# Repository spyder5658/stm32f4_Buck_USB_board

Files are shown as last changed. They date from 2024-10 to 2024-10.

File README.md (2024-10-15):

# STM32F4-Based 4 layered Board with Dual Power Supply and Protection Features
## Overview
This project showcases a custom STM32F4-based board designed with robust power management and advanced PCB architecture. The board features dual power supply options, reverse polarity protection, a buck converter, and a power indicator LED. Additionally, it boasts a 4-layer PCB design, enhancing signal integrity and ensuring efficient power distribution, making it ideal for high-performance embedded systems.

## Key Features
- Microcontroller: STM32F4 series (ARM Cortex-M4)
- 4-Layer PCB Design:
  - Improved signal integrity and EMI performance.
  - Enhanced power distribution for more stable operation.
- Dual Power Supply Options:
- USB-powered for convenient operation.
- Battery-powered for portable applications.
- Reverse Polarity Protection: Protects the circuit from damage due to incorrect battery polarity.
- Buck Converter: Efficient DC-DC conversion to supply the STM32F4 and other peripherals.
- Power-On LED: Visual indicator to confirm that the board is powered.

## Snapshots
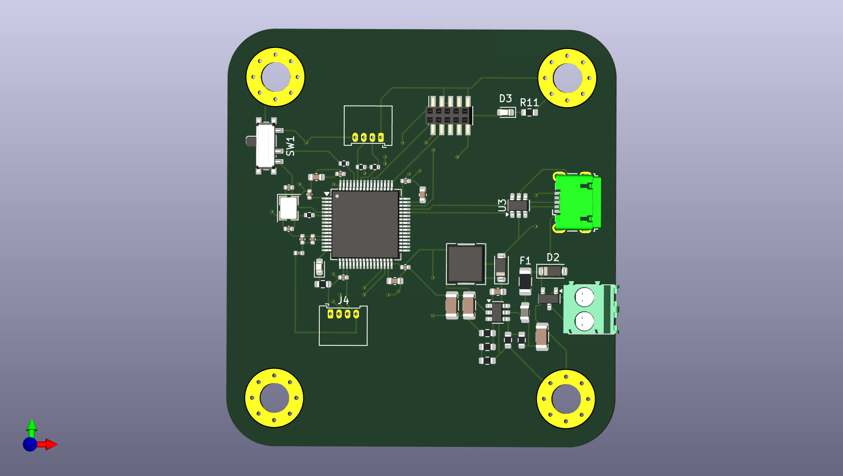
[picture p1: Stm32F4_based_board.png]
STM32F4 Based Board

## Applications
- Prototyping and development of embedded systems.
- IoT (Internet of Things) applications requiring reliable power management.
- Low-power, battery-operated devices.
- Educational and research projects on embedded systems.
## Power Supply Details
- USB Power: Provides power through the standard USB connector.
- Battery Power: Connect a battery for portable applications. The board includes a reverse polarity protection circuit to safeguard against incorrect battery connections.
- Buck Converter: The on-board buck converter ensures efficient power delivery, stepping down the battery voltage to the required level for the STM32F4.

## Powering the Board:
Plug in via USB for direct power.
Alternatively, connect a battery (ensure proper polarity).
The Power-On LED will light up if powered correctly.
## Programming the STM32F4:
Use ST-Link or DFU for firmware uploading.
Refer to the STM32CubeIDE Documentation for setting up your development environment.
## Flashing the Firmware:
To flash the firmware onto the STM32F4, use the following:
```
st-flash write firmware.bin 0x08000000
Replace firmware.bin with your compiled binary file.
```

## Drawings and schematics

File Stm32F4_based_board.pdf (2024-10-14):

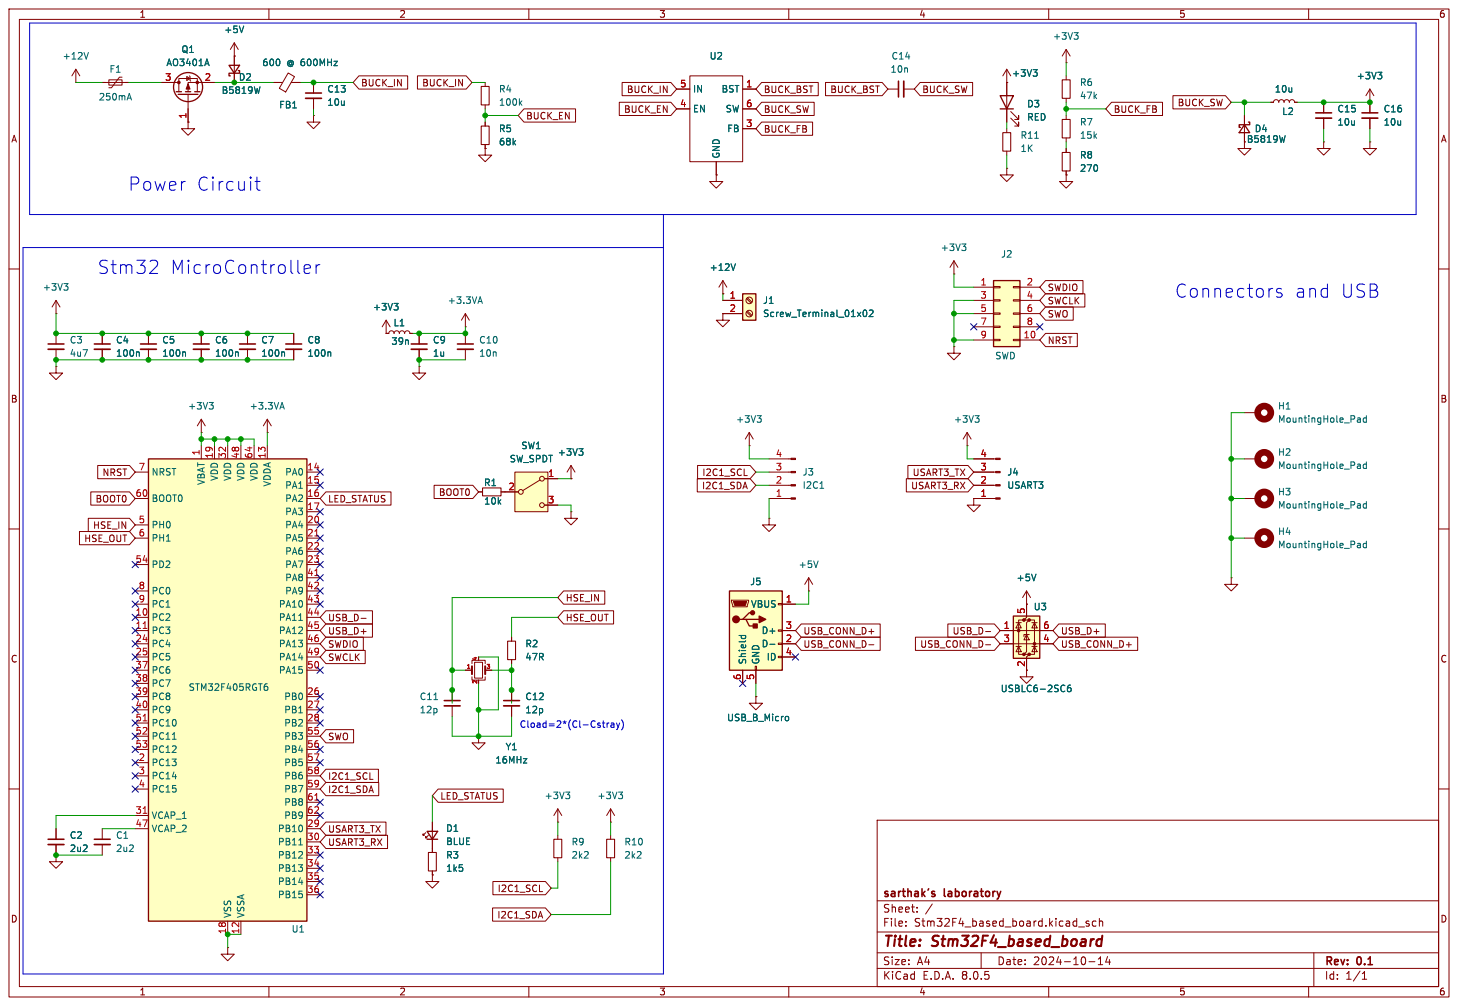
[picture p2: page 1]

1 PC2 10 PC3 11 VSSA 12 VDDA 13 PA0 14 PA1 15 PA2 16 PA3 17 VSS 18 VDD 19 PC13 2 PA4 20 PA5 21 PA6 22 PA7 23 PC4 24 PC5 25 PB0 26 PB1 27 PB2 28 PB10 29 PC14 3 PB11 30 VCAP_1 31 VDD 32 PB12 33 PB13 34 PB14 35 PB15 36 PC6 37 PC7 38 PC8 39 PC15 4 PC9 40 PA8 41 PA9 42 PA10 43 PA11 44 PA12 45 PA13 46 VCAP_2 47 VDD 48 PA14 49 PH0 5 PA15 50 PC10 51 PC11 52 PC12 53 PD2 54 PB3 55 PB4 56 PB5 57 PB6 58 PB7 59 PH1 6 BOOT0 60 PB8 61 PB9 62 VDD 64 NRST 7 PC0 8 PC1 9 U1 STM32F405RGT6 R2

File: Stm32F4_based_board.kicad_sch Sheet: / sarthak's laboratory

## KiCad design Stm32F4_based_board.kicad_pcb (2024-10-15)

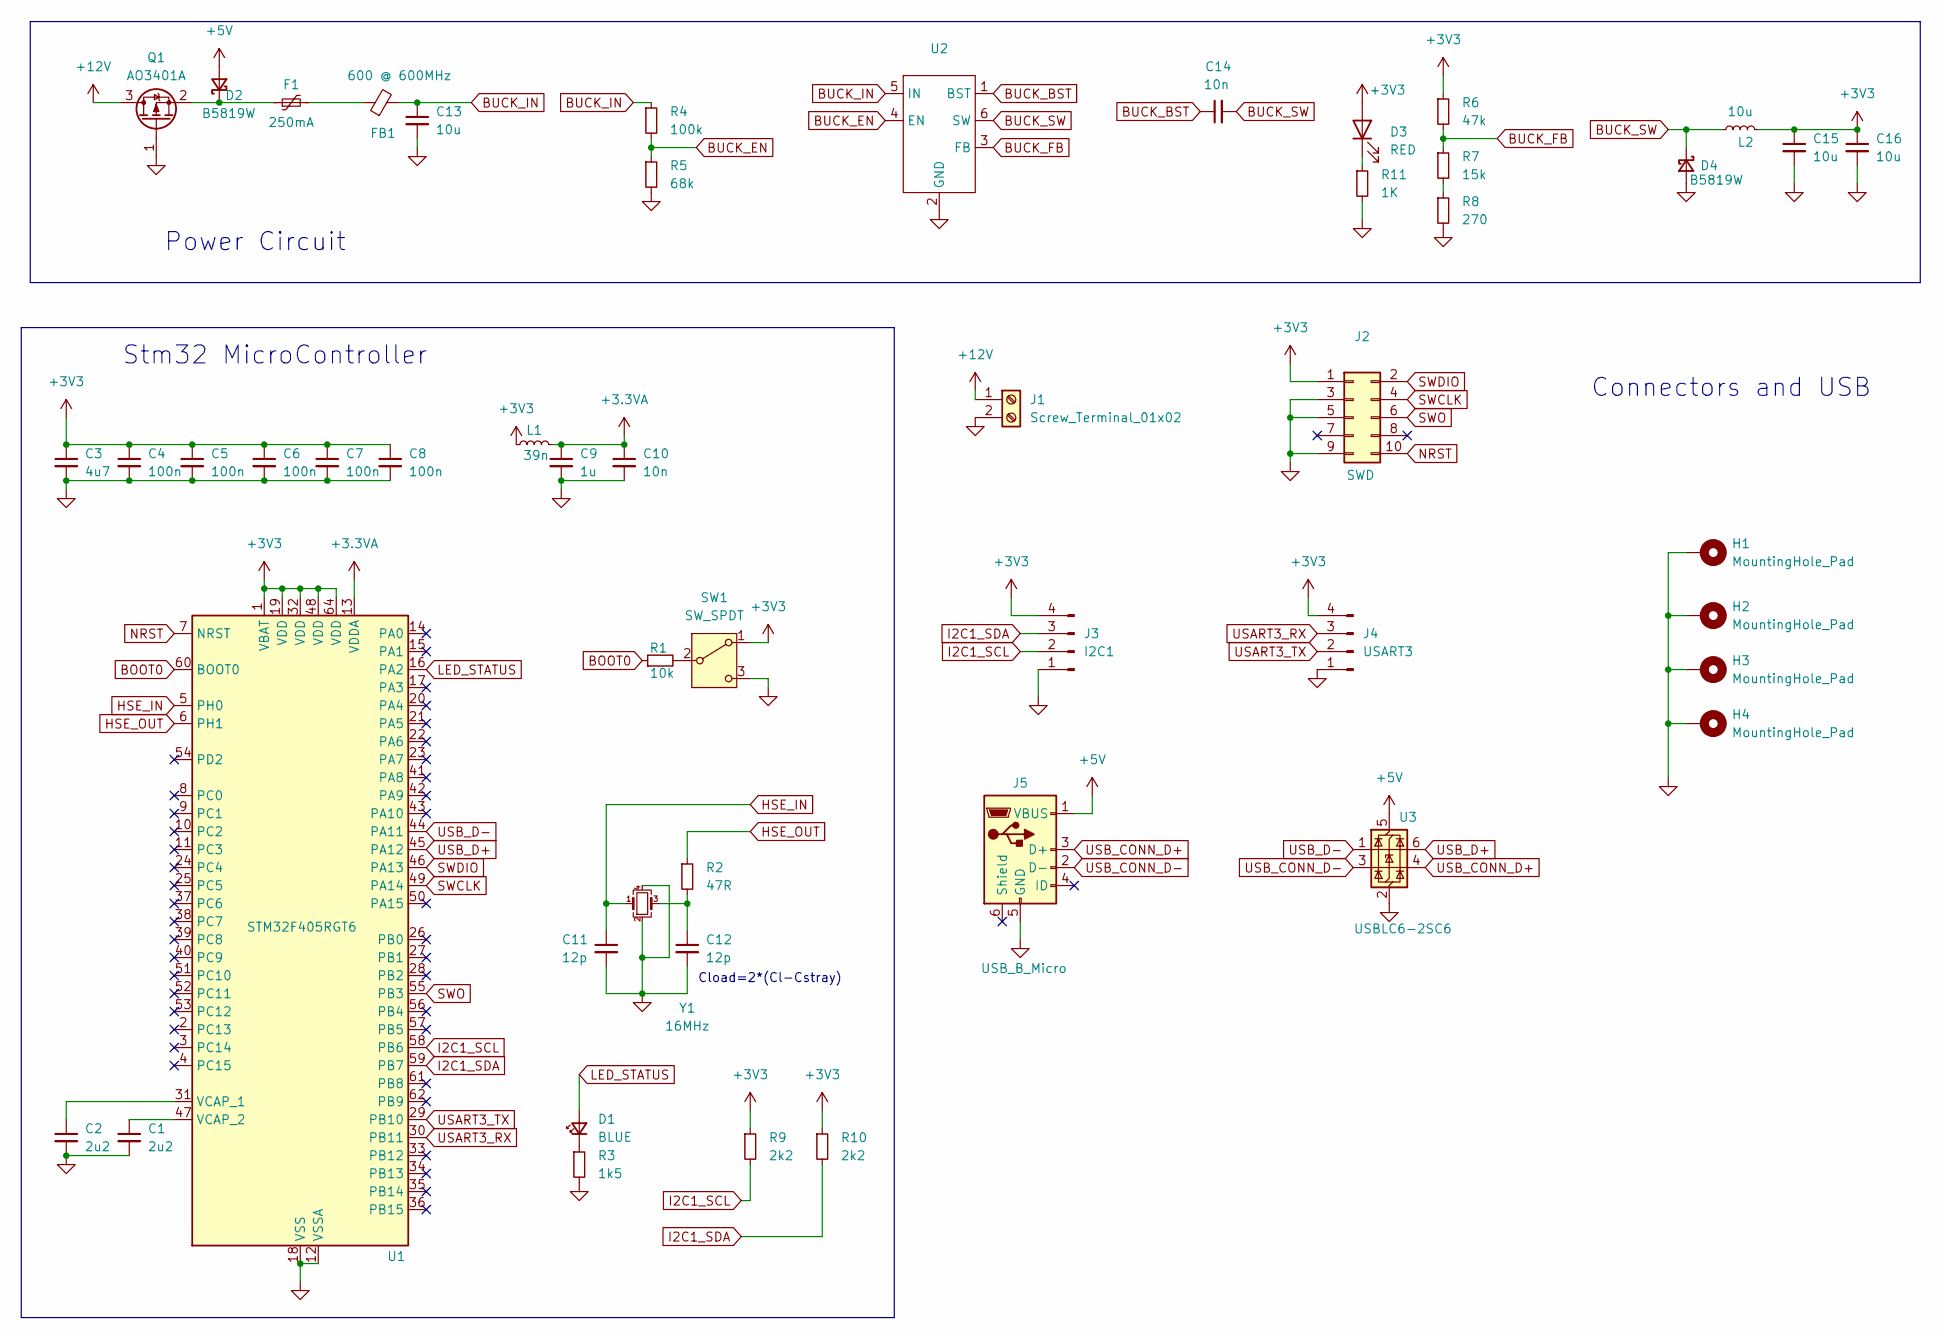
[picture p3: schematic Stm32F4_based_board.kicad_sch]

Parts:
C1, C2: 2u2; C_0603_1608Metric
C3: 4u7; C_0603_1608Metric
C4, C5, C6, C7, C8: 100n; C_0402_1005Metric
C9: 1u; C_0402_1005Metric
C10: 10n; C_0402_1005Metric
C11, C12: 12p; C_0402_1005Metric
C13, C15, C16: 10u; C_1206_3216Metric
C14: 10n; C_0603_1608Metric
D1: BLUE; LED_0603_1608Metric
D2, D4: B5819W; D_SOD-123
D3: RED; LED_0603_1608Metric
F1: 250mA; Fuse_1206_3216Metric
FB1: 600 @ 600MHz; L_0805_2012Metric
H1, H2, H3, H4: MountingHole_Pad; MountingHole_4.3mm_M4_Pad_Via
J1: Screw_Terminal_01x02; TerminalBlock_Phoenix_PT-1,5-2-3.5-H_1x02_P3.50mm_Horizontal
J2: SWD; PinSocket_2x05_P1.27mm_Vertical_SMD
J3: I2C1; Molex_PicoBlade_53048-0410_1x04_P1.25mm_Horizontal
J4: USART3; Molex_PicoBlade_53048-0410_1x04_P1.25mm_Horizontal
J5: USB_B_Micro; USB_Micro-B_Wuerth_629105150521
L1: 39n; L_0402_1005Metric
L2: 10u; L_Sunlord_MWSA0518S
Q1: AO3401A; SOT-23
R1: 10k; R_0402_1005Metric
R2: 47R; R_0402_1005Metric
R3: 1k5; R_0603_1608Metric
R4: 100k; R_0603_1608Metric
R5: 68k; R_0603_1608Metric
R6: 47k; R_0603_1608Metric
R7: 15k; R_0603_1608Metric
R8: 270; R_0603_1608Metric
R9, R10: 2k2; R_0402_1005Metric
R11: 1K; R_0603_1608Metric
SW1: SW_SPDT; SW_SPDT_PCM12
U1: STM32F405RGT6; LQFP-64_10x10mm_P0.5mm
U2: SOT-23-6
U3: USBLC6-2SC6; SOT-23-6
Y1: 16MHz; Crystal_SMD_3225-4Pin_3.2x2.5mm

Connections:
+3.3VA: C9.1, C10.1, L1.2, U1.13 (VDDA)
+3V3: C3.1, C4.1, C5.1, C6.1, C7.1, C8.1, C15.1, C16.1, D3.2 (A), J2.1, J3.4, J4.4, L1.1, L2.2, R6.1, R9.1, R10.1, SW1.1 (A), U1.1 (VBAT), U1.19 (VDD), U1.32 (VDD), U1.48 (VDD), U1.64 (VDD)
+5V: D2.2 (A), J5.1 (VBUS), U3.5 (VBUS)
+12V: J1.1, Q1.3 (D)
BOOT0: R1.1, U1.60 (BOOT0)
BUCK_BST: C14.1, U2.1 (BST)
BUCK_EN: R4.2, R5.1, U2.4 (EN)
BUCK_FB: R6.2, R7.1, U2.3 (FB)
BUCK_IN: C13.1, FB1.2, R4.1, U2.5 (IN)
BUCK_SW: C14.2, D4.1 (K), L2.1, U2.6 (SW)
GND: C1.2, C2.2, C3.2, C4.2, C5.2, C6.2, C7.2, C8.2, C9.2, C10.2, C11.2, C12.2, C13.2, C15.2, C16.2, D4.2 (A), H1.1, H2.1, H3.1, H4.1, J1.2, J2.3, J2.5, J2.9, J3.1, J4.1, J5.5 (GND), Q1.1 (G), R3.2, R5.2, R8.2, R11.2, SW1.3 (C), U1.12 (VSSA), U1.18 (VSS), U1.63 (VSS), U2.2 (GND), U3.2 (GND), Y1.2, Y1.4
HSE_IN: C11.1, U1.5 (PH0), Y1.1
HSE_OUT: R2.1, U1.6 (PH1)
I2C1_SCL: J3.2, R9.2, U1.58 (PB6)
I2C1_SDA: J3.3, R10.2, U1.59 (PB7)
LED_STATUS: D1.2 (A), U1.16 (PA2)
NRST: J2.10, U1.7 (NRST)
unnamed: C12.1, R2.2, Y1.3
unnamed: D1.1 (K), R3.1
unnamed: D2.1 (K), F1.1, Q1.2 (S)
unnamed: D3.1 (K), R11.1
unnamed: F1.2, FB1.1
unnamed: R7.2, R8.1
unnamed: R1.2, SW1.2 (B)
unnamed: C2.1, U1.31 (VCAP_1)
unnamed: C1.1, U1.47 (VCAP_2)
SWCLK: J2.4, U1.49 (PA14)
SWDIO: J2.2, U1.46 (PA13)
SWO: J2.6, U1.55 (PB3)
USART3_RX: J4.3, U1.30 (PB11)
USART3_TX: J4.2, U1.29 (PB10)
USB_CONN_D+: J5.3 (D+), U3.4 (I/O2)
USB_CONN_D-: J5.2 (D-), U3.3 (I/O2)
USB_D+: U1.45 (PA12), U3.6 (I/O1)
USB_D-: U1.44 (PA11), U3.1 (I/O1)

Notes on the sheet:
Power Circuit
Stm32 MicroController
Connectors and USB
Cload=2*(Cl-Cstray)

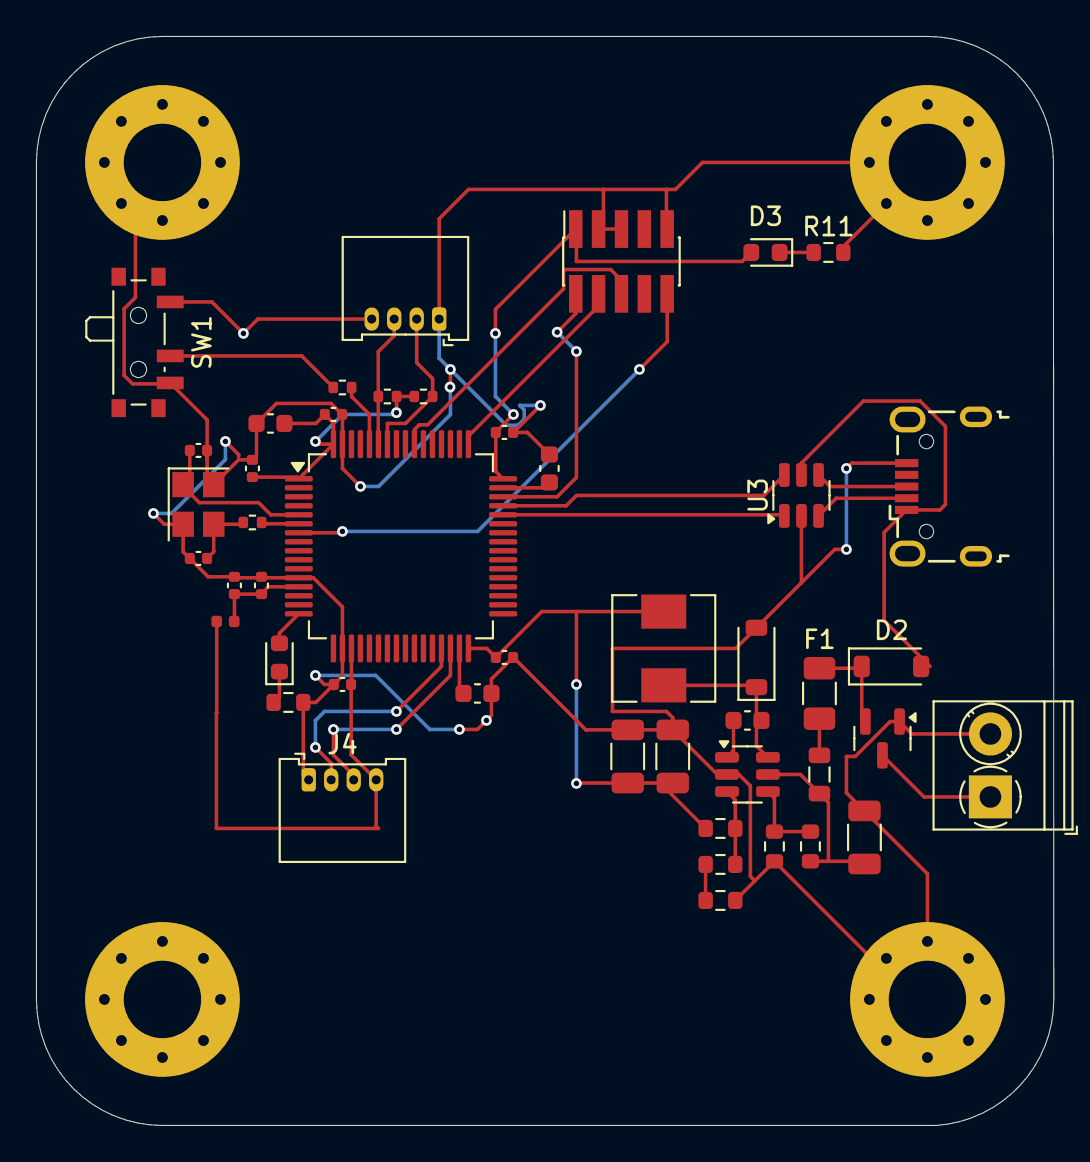
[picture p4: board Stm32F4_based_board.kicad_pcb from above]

Board: 4 copper layers, 56.5 x 60.5 mm, 50 parts (0 on the bottom side), 35 nets.

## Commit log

2024-10-14 schematic of the stm32f4 based board completed
    [Stm32F4_based_board.kicad_pcb, Stm32F4_based_board.kicad_sch]
2024-10-15 updated into PCB with the usb 3d model
    [Stm32F4_based_board.kicad_pcb, Stm32F4_based_board.kicad_sch]
